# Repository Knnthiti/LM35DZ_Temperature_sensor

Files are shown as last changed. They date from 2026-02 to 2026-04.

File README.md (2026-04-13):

# Zero and Span Adjustment Circuit for LM35 Temperature Sensor

โปรเจกต์นี้เป็นการออกแบบและสร้างวงจรปรับแต่งสัญญาณ (Signal Conditioning) เพื่อแปลงแรงดันจากเซนเซอร์ **LM35** ให้เหมาะสมกับ ADC ของ Microcontroller โดยค่าที่ได้จากการทดลองอยู่ในช่วงประมาณ **0.218V – 0.507V** และแปลงเป็นค่า ADC ได้ประมาณ **0.64 – 3.10**

## 📐 รายละเอียดการคำนวณ (Calculation)

ข้อมูลในหัวข้อนี้อ้างอิงจาก **ผลการทดลองจริง** โดยสามารถดูแหล่งข้อมูลได้จากไฟล์ **กราฟการทดลอง.xlsx**

### 1. วิเคราะห์สัญญาณขาเข้า (Input Analysis)
ค่าที่วัดได้จากการทดลองจริงมีดังนี้:

| อุณหภูมิ (°C) | แรงดัน (V) | ADC |
|---:|---:|---:|
| 50 | 0.507 | 3.10 |
| 45 | 0.454 | 2.82 |
| 40 | 0.403 | 2.35 |
| 35 | 0.355 | 1.94 |
| 30 | 0.312 | 1.51 |
| 25 | 0.253 | 1.00 |
| 20 | 0.218 | 0.64 |

### 2. สมการเส้นตรง (Transfer Function)
ใช้รูปแบบสมการเส้นตรงแบบเดิมคือ
$$y = mx + c$$

โดย
- $m$ คือความชัน (Slope)
- $c$ คือจุดตัดแกน $y$ (Offset)

**2.1 การหาสมการ V_to_ADC**

กำหนดให้ $x = V$ และ $y = ADC$

- แทนค่าจากข้อมูลจริงในไฟล์ **กราฟการทดลอง.xlsx** (ใช้จุดปลายช่วงวัด)
  - จุดที่ 1: $(V, ADC) = (0.218, 0.64)$
  - จุดที่ 2: $(V, ADC) = (0.507, 3.10)$

- **หาค่าความชัน (Slope) แบบเดิม:**
  $$m = \frac{\Delta ADC}{\Delta V} = \frac{3.10 - 0.64}{0.507 - 0.218} = \frac{2.46}{0.289} = 8.5121$$

- **หาค่าออฟเซต (Intercept):**
  แทนค่าใน $y = mx + c$ ด้วยจุด $(0.218, 0.64)$
  $$0.64 = (8.5121 \times 0.218) + c$$
  $$0.64 = 1.8556 + c$$
  $$c = 0.64 - 1.8556 = -1.2156$$

- ตรวจสอบกับเส้นแนวโน้ม (Linear Trendline) จะได้ค่าเดียวกันคือ
  $$m = 8.5121,\; c = -1.2156$$

ดังนั้นสมการคือ
$$ADC = 8.5121V - 1.2156$$

**2.2 การหาสมการ ADC_to_C**

กำหนดให้ $x = ADC$ และ $y = C$

- จากการทำเส้นแนวโน้ม (Linear Trendline) ในไฟล์ **กราฟการทดลอง.xlsx** ได้ค่า
  $$m = 11.336,\; c = 13.106$$

ดังนั้นสมการคือ
$$C = 11.336(ADC) + 13.106$$

**สรุปสมการจากข้อมูลทดลองจริง (พร้อมกราฟ):**

1. **V_to_ADC**
   $$ADC = 8.5121V - 1.2156$$

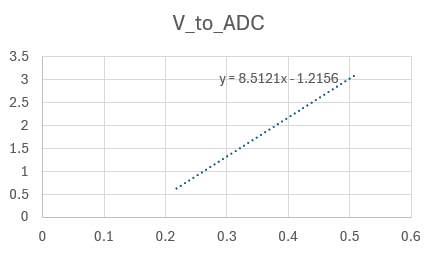
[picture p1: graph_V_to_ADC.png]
กราฟ V_to_ADC จากการทดลองจริง
   

2. **ADC_to_C**
   $$C = 11.336(ADC) + 13.106$$

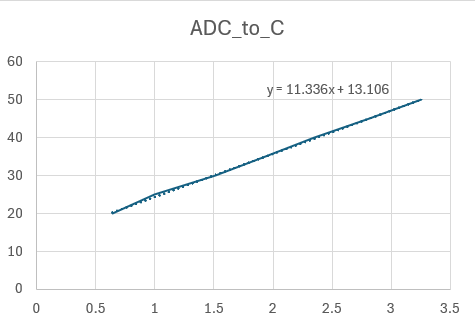
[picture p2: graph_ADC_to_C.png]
กราฟ ADC_to_C จากการทดลองจริง
   

จากภาพด้านบน ค่าที่ใช้ใน README เป็นค่าจริงจากการทดลอง และสามารถตรวจสอบรายละเอียดได้จากไฟล์ **กราฟการทดลอง.xlsx**

---

## 🛠 โครงสร้างและการทำงานของวงจร

วงจรนี้ใช้ Op-Amp **LM358** ในการจัดการสัญญาณ แบ่งออกเป็นส่วนต่างๆ ดังนี้:

- **Sensor Input:** รับสัญญาณจาก LM35-LP ที่ไฟเลี้ยง 3.3V
- **Input Buffer (U2A):** ทำหน้าที่เป็น Voltage Follower เพื่อแยกโหลดออกจากตัวเซนเซอร์
- **Zero Adjustment (U3A):** ใช้ Potentiometer (RV1) เพื่อปรับแรงดันอ้างอิง (Reference Voltage) สำหรับชดเชยค่า Offset
- **Span Adjustment (U3B):** ปรับอัตราขยาย (Gain) เพื่อให้ได้ช่วงแรงดันที่ต้องการ (Span)
- **Output:** สัญญาณ $V_{out}$ จะถูกส่งออกทาง Connector J1

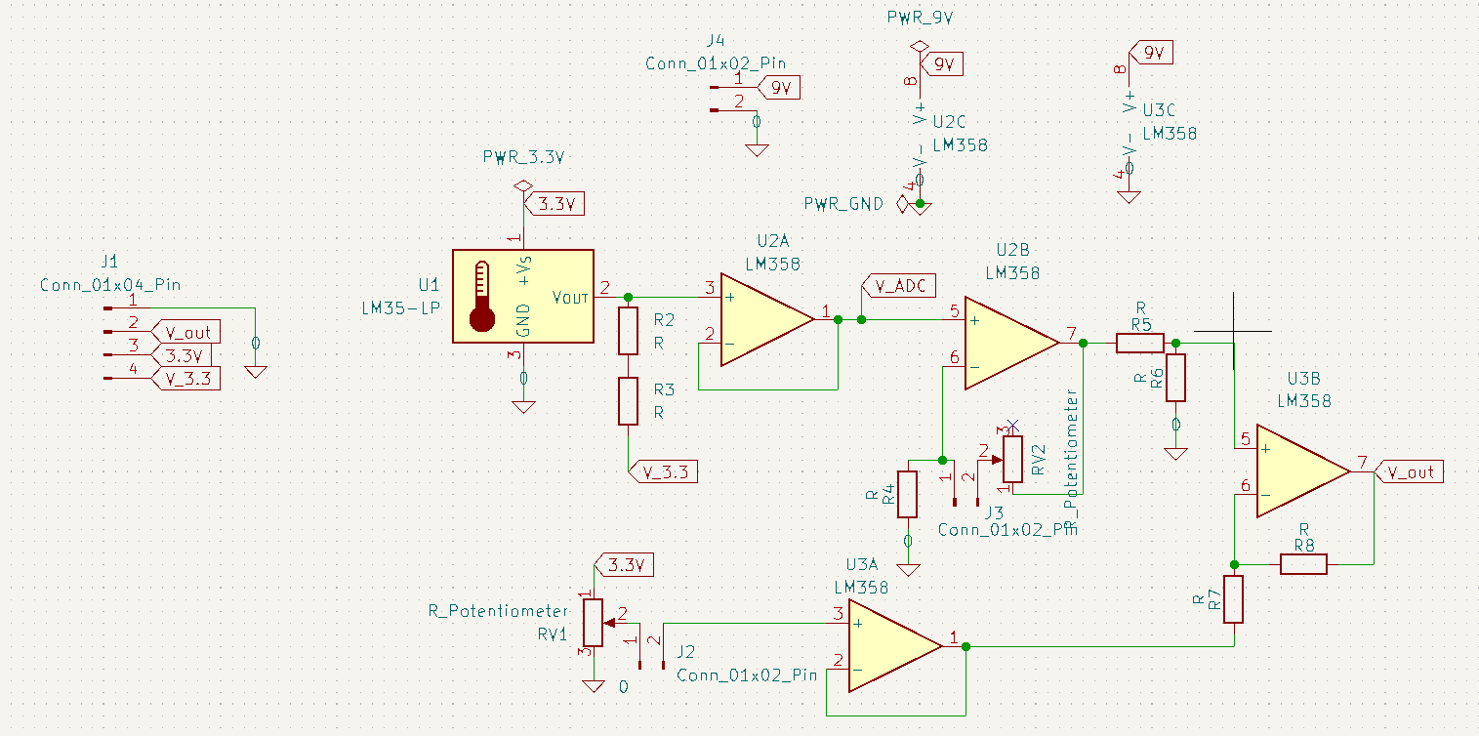
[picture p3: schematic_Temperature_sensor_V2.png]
Operational amplifier differential amplifier circuit diagram


## 📊 ระบบแสดงข้อมูล (Display System)

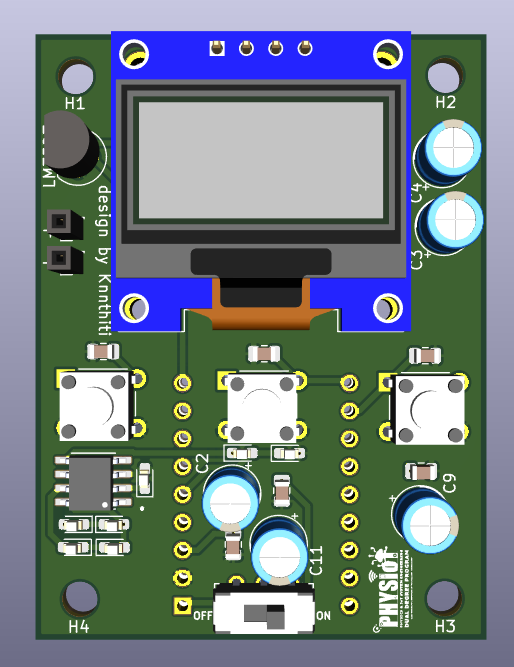
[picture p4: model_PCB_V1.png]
3D model overview


ระบบแสดงผลถูกแบ่งเป็น 3 โหมดตามปุ่มควบคุม ดังนี้:
- **ปุ่มซ้าย:** เข้าโหมด **WiFi Manager** และเมื่อเชื่อมต่อเครือข่ายสำเร็จ ระบบจะแสดง **IP Address** สำหรับเชื่อมต่อผ่าน **WebSocket**
- **ปุ่มกลาง:** แสดงค่า **อุณหภูมิ** ที่วัดได้จากเซนเซอร์
- **ปุ่มขวา:** แสดงค่า **แรงดันไฟฟ้า** ของสัญญาณที่วัดได้

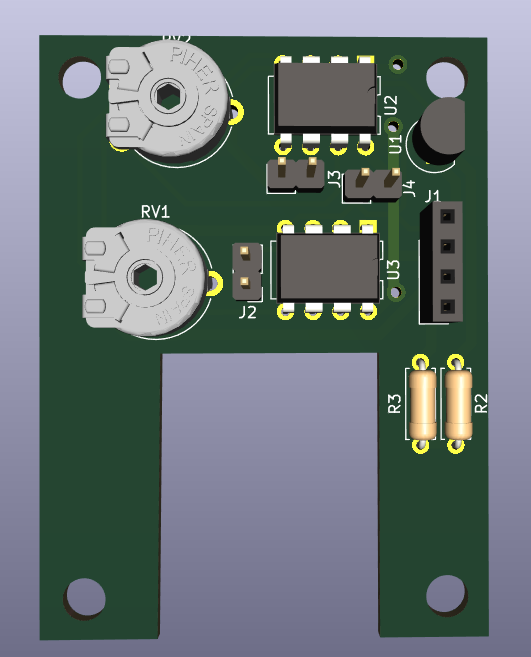
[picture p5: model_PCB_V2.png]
3D model overview


เป็น Zero and span adjustment circuit :
- **R ตัวบน:** เป็น Rf ปรับกำลังขยาย
- **R ตัวล่าง:** เป็น span ปรับแรงดัน

โค้ดโปรแกรมสามารถดูได้ที่ไฟล์ `T_sensor_V3/T_sensor_V3.ino`

---

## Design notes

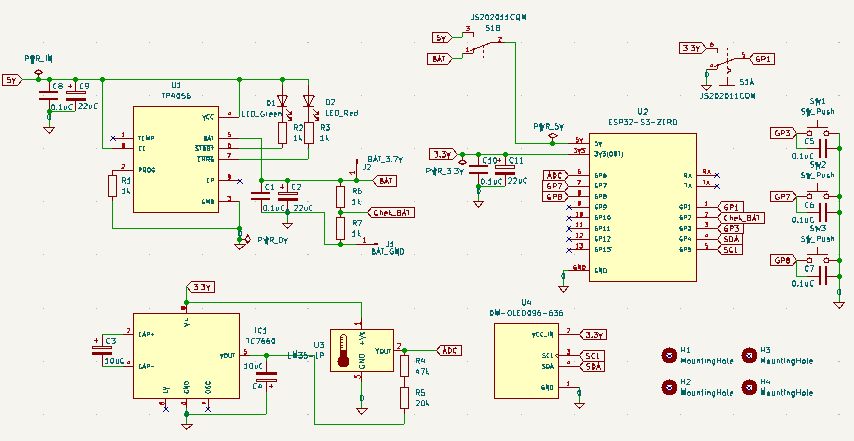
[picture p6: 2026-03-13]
schematic_Temperature_sensor_V1.png

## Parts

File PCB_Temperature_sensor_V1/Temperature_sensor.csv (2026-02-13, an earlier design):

Source: | C:\Users\Knnn\Desktop\LM35DZ_Temperature_sensor\Temperature_sensor\Temperature_sensor.kicad_sch
Date: | 2026-02-13T22:16:05+0700
Tool: | Eeschema 8.0.5
Generator: | C:\Users\Knnn\AppData\Local\Programs\KiCad\8.0\bin\scripting\plugins/bom_csv_grouped_by_value_with_fp.py
Component Count: | 31
Ref | Qnty | Value | Cmp name | Footprint | Description | Vendor | DNP
C1, C5, C6, C7, C8, C10 | 6 | 0.1uC | C | Capacitor_SMD:C_0805_2012Metric | Unpolarized capacitor
C2, C9, C11 | 3 | 22uC | C_Polarized | Capacitor_THT:CP_Radial_D5.0mm_P2.00mm | Polarized capacitor
C3, C4 | 2 | 10uC | C_Polarized | Capacitor_THT:CP_Radial_D5.0mm_P2.00mm | Polarized capacitor
D1 | 1 | LED_Green | LED | LED_SMD:LED_0603_1608Metric_Pad1.05x0.95mm_HandSolder | Light emitting diode
D2 | 1 | LED_Red | LED | LED_SMD:LED_0603_1608Metric_Pad1.05x0.95mm_HandSolder | Light emitting diode
IC1 | 1 | TC7660 | TC7660 | TC7660:TC7660
J1 | 1 | BAT_GND | Conn_01x01_Pin | Connector_PinSocket_2.00mm:PinSocket_1x01_P2.00mm_Vertical | Generic connector, single row, 01x01, script generated
J2 | 1 | BAT_3.7V | Conn_01x01_Pin | Connector_PinSocket_2.00mm:PinSocket_1x01_P2.00mm_Vertical | Generic connector, single row, 01x01, script generated
R1, R2, R3, R6, R7 | 5 | 1k | R | LED_SMD:LED_0603_1608Metric_Pad1.05x0.95mm_HandSolder | Resistor
R4 | 1 | 47k | R | Resistor_THT:R_Axial_DIN0207_L6.3mm_D2.5mm_P10.16mm_Horizontal | Resistor
R5 | 1 | 20k | R | Resistor_THT:R_Axial_DIN0207_L6.3mm_D2.5mm_P10.16mm_Horizontal | Resistor
S1 | 1 | JS202011CQN | JS202011CQN | JS202011CQN:JS202011CQN
SW1, SW2, SW3 | 3 | SW_Push | SW_Push | SW_Push:SW_TH_Tactile_Omron_B3F-10xx | Push button switch, generic, two pins
U1 | 1 | TP4056 | TP4056 | TP4056:SOP127P600X175-9N
U2 | 1 | ESP32-S3-ZERO | ESP32-S3-ZERO | esp32s3Zero:MODULE_ESP32-S3-ZERO
U3 | 1 | LM35-LP | LM35-LP | Package_TO_SOT_THT:TO-92 | Precision centigrade temperature sensor, TO-92
U4 | 1 | DM-OLED096-636 | DM-OLED096-636 | OLED:MODULE_DM-OLED096-636

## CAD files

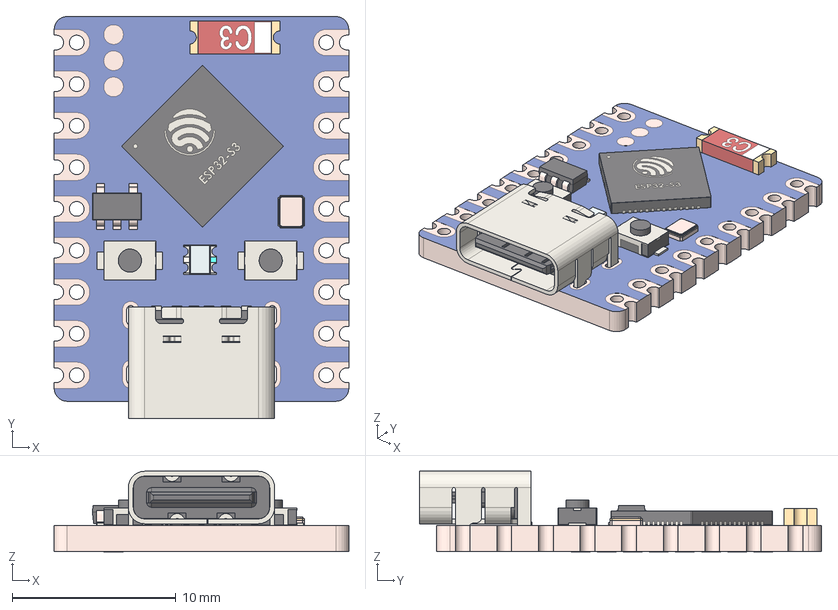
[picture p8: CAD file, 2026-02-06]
Components/esp32s3Zero/ESP32-S3_Zero.step
18.0 x 24.6 x 4.92 mm

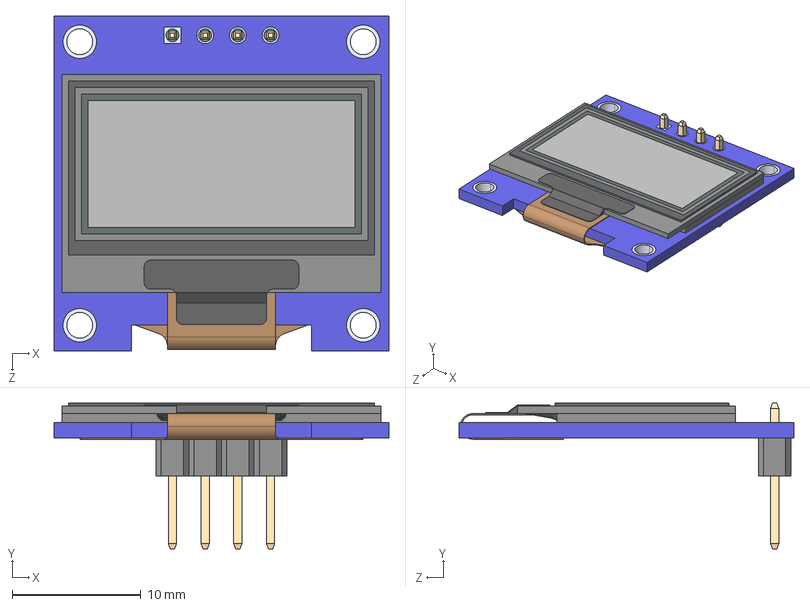
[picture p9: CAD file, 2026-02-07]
Components/OLED/DM-OLED096-636.step
26.0 x 11.3 x 26.0 mm
DM-OLED096-636_Module
DM-OLED096-636_Panel

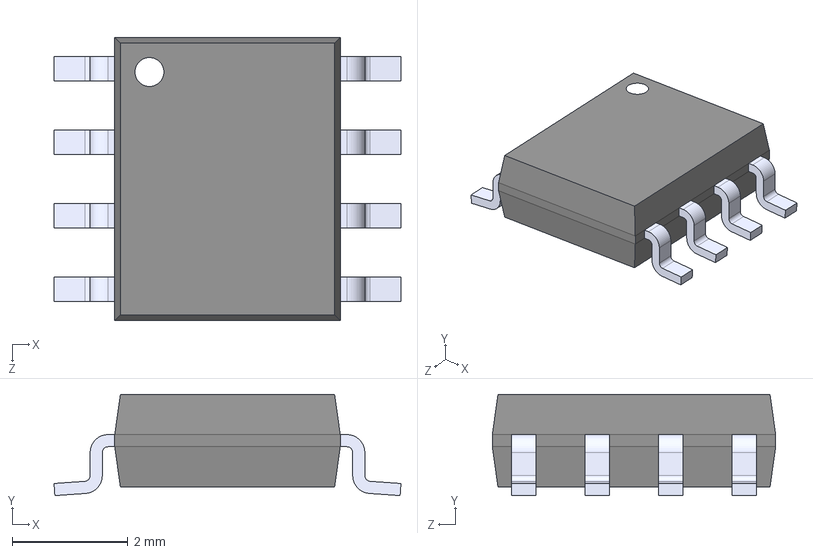
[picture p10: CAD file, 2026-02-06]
Components/TP4056_IC/TP4056.step
6.00 x 1.75 x 4.90 mm

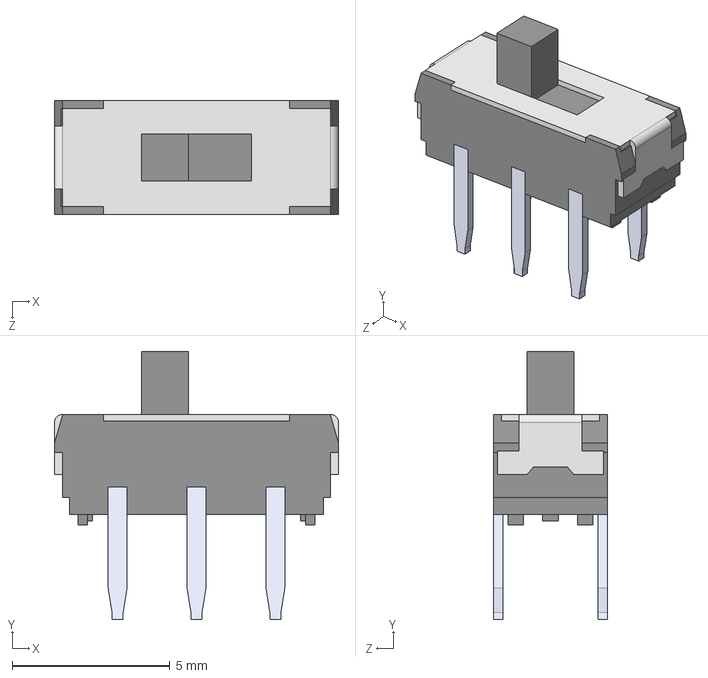
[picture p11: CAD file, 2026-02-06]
Components/swith/JS202011CQN.step
9.00 x 8.50 x 3.60 mm

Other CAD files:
Components/TC7660/dip8_ic.STEP

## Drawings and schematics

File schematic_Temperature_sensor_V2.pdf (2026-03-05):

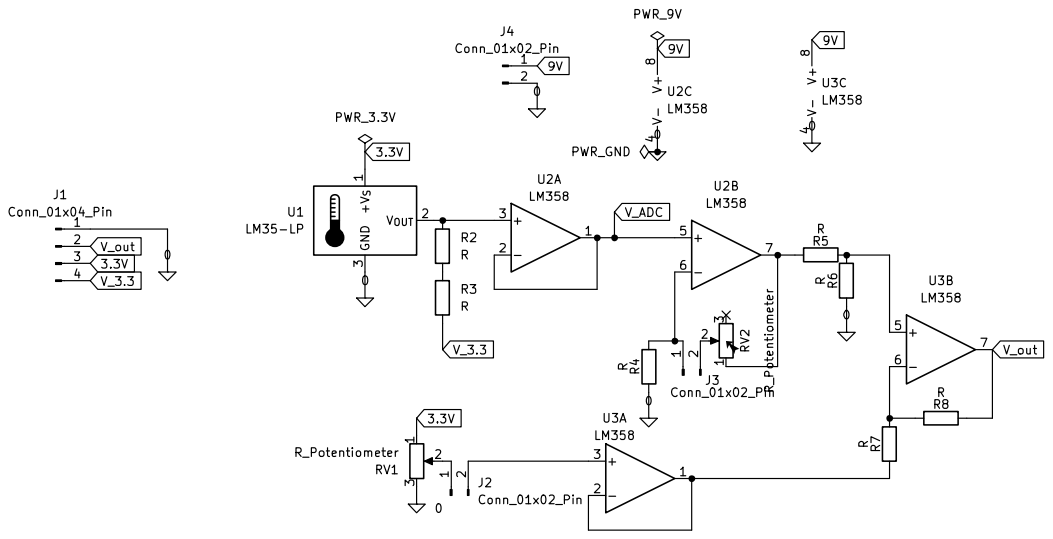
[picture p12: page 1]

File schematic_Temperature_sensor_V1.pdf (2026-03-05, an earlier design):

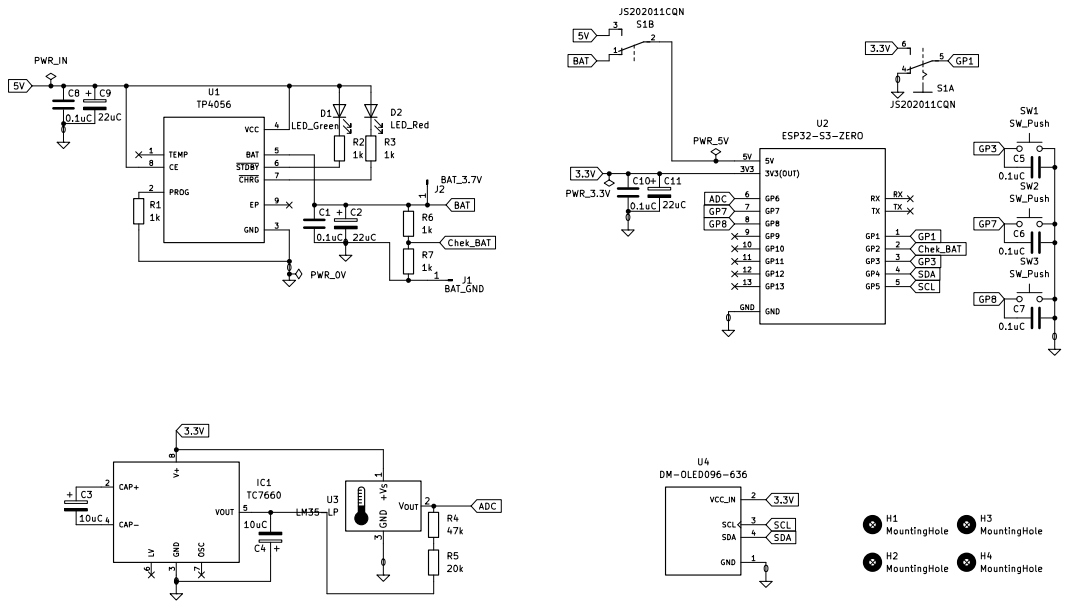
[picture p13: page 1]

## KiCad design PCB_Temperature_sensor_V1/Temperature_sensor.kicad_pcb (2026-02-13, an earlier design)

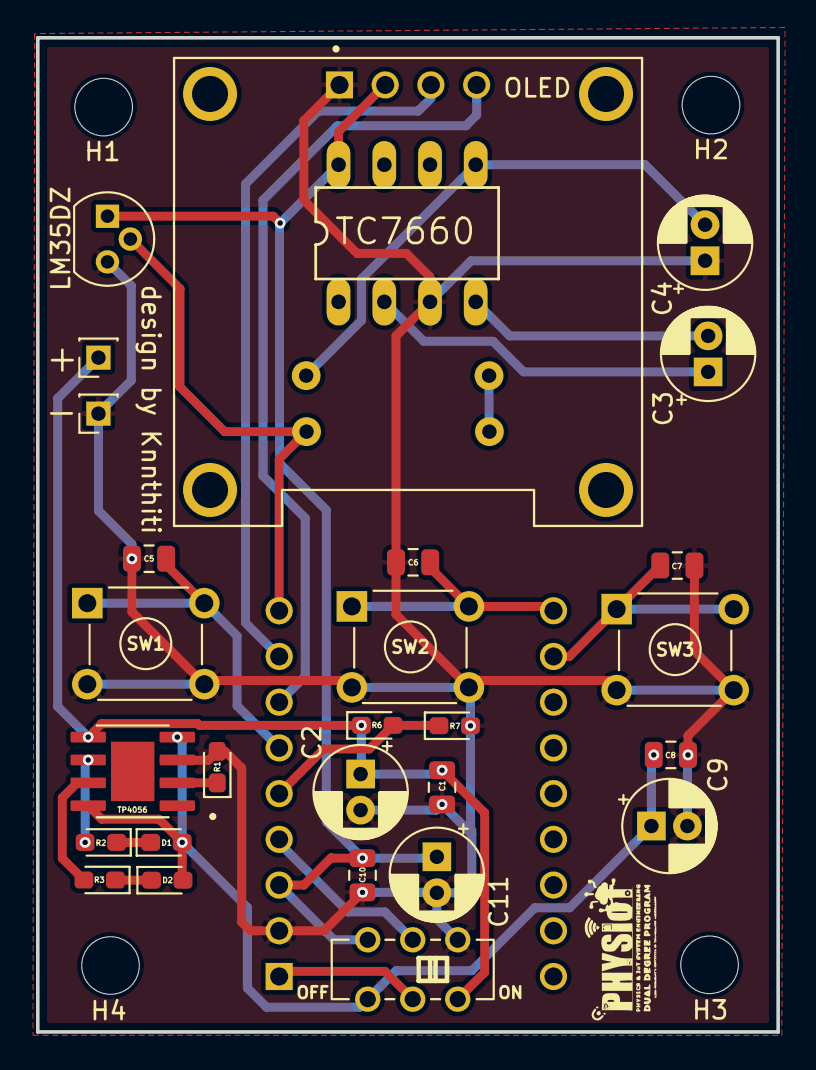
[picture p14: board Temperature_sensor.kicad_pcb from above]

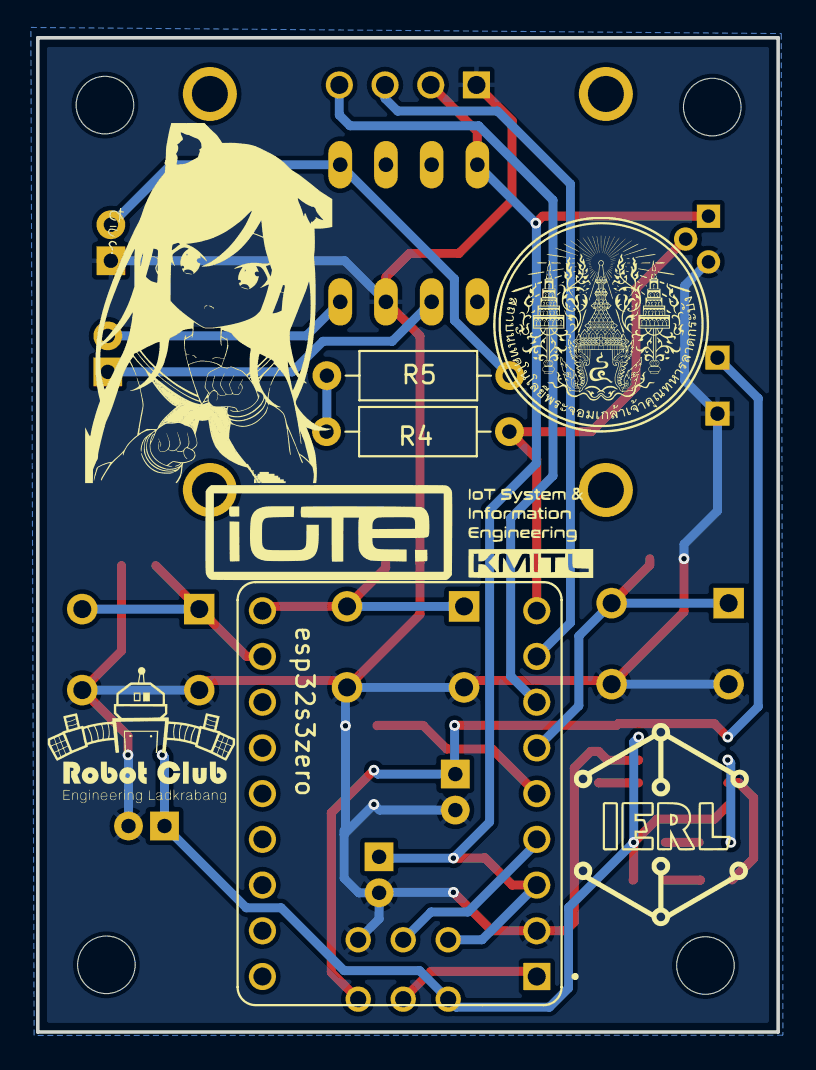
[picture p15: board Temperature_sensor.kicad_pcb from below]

Board: 2 copper layers, 41.1 x 55.2 mm, 35 parts (3 on the bottom side), 22 nets.

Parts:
+: BAT_3.7V; PinSocket_1x01_P2.00mm_Vertical
-: BAT_GND; PinSocket_1x01_P2.00mm_Vertical
C1, C5, C6, C7, C8, C10: 0.1uC; C_0805_2012Metric
C2, C9, C11: 22uC; CP_Radial_D5.0mm_P2.00mm
C3, C4: 10uC; CP_Radial_D5.0mm_P2.00mm
D1: LED_Green; LED_0603_1608Metric_Pad1.05x0.95mm_HandSolder
D2: LED_Red; LED_0603_1608Metric_Pad1.05x0.95mm_HandSolder
H1, H2, H3, H4: MountingHole; MountingHole_3.2mm_M3
LM35DZ: LM35-LP; TO-92
OFF                   ON: JS202011CQN
OLED: DM-OLED096-636; MODULE_DM-OLED096-636
R1, R2, R3, R6, R7: 1k; LED_0603_1608Metric_Pad1.05x0.95mm_HandSolder
R4: 47k; R_Axial_DIN0207_L6.3mm_D2.5mm_P10.16mm_Horizontal
R5: 20k; R_Axial_DIN0207_L6.3mm_D2.5mm_P10.16mm_Horizontal
SW1, SW2, SW3: SW_Push; SW_TH_Tactile_Omron_B3F-10xx
TC7660: TC7660
TP4056: TP4056; SOP127P600X175-9N
esp32s3zero: ESP32-S3-ZERO; MODULE_ESP32-S3-ZERO

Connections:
0: -.1, C1.2, C2.2, C4.1, C5.2, C6.2, C7.2, C8.2, C9.2, C10.2, C11.2, LM35DZ.3 (GND), OFF ON.4, OLED.1 (GND), R1.2, R7.2, SW1.2, SW2.2, SW3.2, TC7660.3 (GND), TP4056.3 (GND), esp32s3zero.GND
3.3V: C10.1, C11.1, LM35DZ.1 (+V_{S}), OFF ON.6, OLED.2 (VCC_IN), TC7660.8 (V+), esp32s3zero.3V3 (3V3(OUT))
5V: C8.1, C9.1, D1.2 (A), D2.2 (A), OFF ON.3, TP4056.4 (VCC), TP4056.8 (CE)
ADC: LM35DZ.2 (V_{OUT}), R4.1, esp32s3zero.6 (GP6)
BAT: +.1, C1.1, C2.1, OFF ON.1, R6.1, TP4056.5 (BAT)
Chek_BAT: R6.2, R7.1, esp32s3zero.2 (GP2)
GP1: OFF ON.5, esp32s3zero.1 (GP1)
GP3: C5.1, SW1.1, esp32s3zero.3 (GP3)
GP7: C6.1, SW2.1, esp32s3zero.7 (GP7)
GP8: C7.1, SW3.1, esp32s3zero.8 (GP8)
unnamed: D1.1 (K), R2.1
unnamed: D2.1 (K), R3.1
unnamed: C3.1, TC7660.2 (CAP+)
unnamed: C3.2, TC7660.4 (CAP-)
unnamed: C4.2, R5.2, TC7660.5 (VOUT)
unnamed: R4.2, R5.1
unnamed: OFF ON.2, esp32s3zero.5V
unnamed: R1.1, TP4056.2 (PROG)
unnamed: R3.2, TP4056.7 (~CHRG)
unnamed: R2.2, TP4056.6 (~STDBY)
SCL: OLED.3 (SCL), esp32s3zero.5 (GP5)
SDA: OLED.4 (SDA), esp32s3zero.4 (GP4)

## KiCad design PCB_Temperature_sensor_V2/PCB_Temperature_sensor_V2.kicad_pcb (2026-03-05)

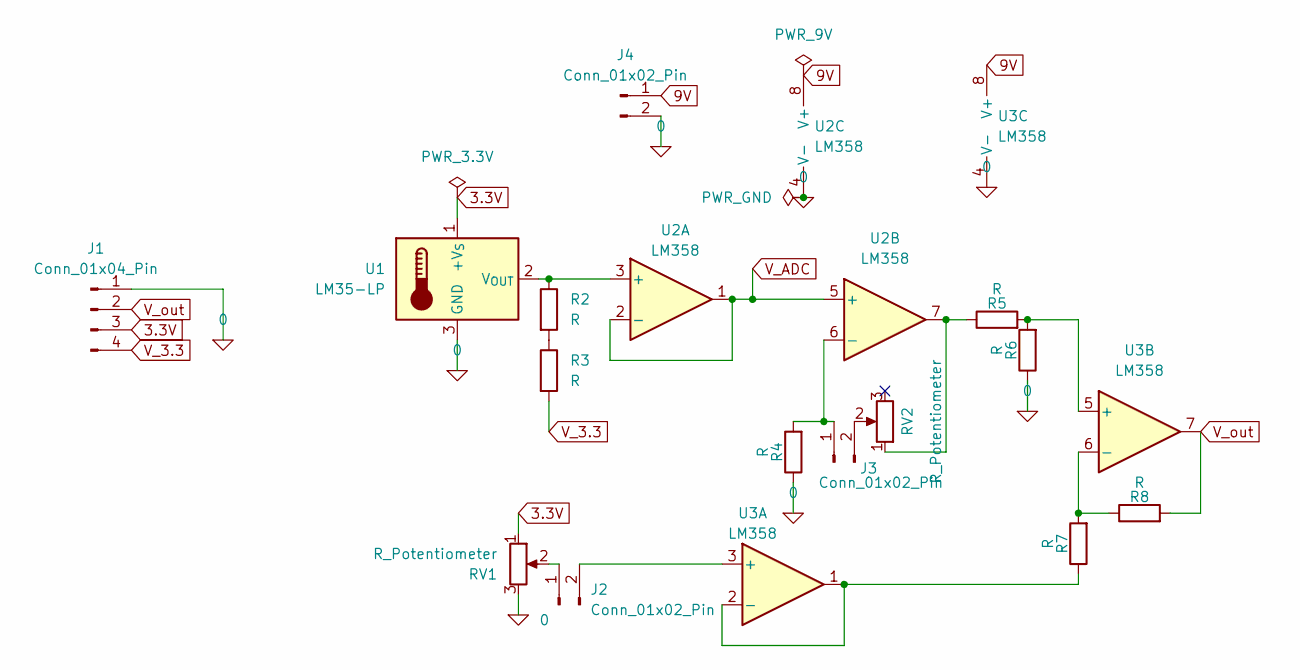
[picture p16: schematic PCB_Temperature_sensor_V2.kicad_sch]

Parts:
J1: Conn_01x04_Pin; PinSocket_1x04_P2.54mm_Vertical
J2, J3, J4: Conn_01x02_Pin; PinHeader_1x02_P2.54mm_Vertical
R2, R3: R; R_Axial_DIN0207_L6.3mm_D2.5mm_P7.62mm_Horizontal
R4, R5, R6, R7, R8: R; R_0603_1608Metric_Pad0.98x0.95mm_HandSolder
RV1, RV2: R_Potentiometer; Potentiometer_Piher_PT-10-V10_Vertical
U1: LM35-LP; TO-92_Inline
U2, U3: LM358; DIP-8_W7.62mm

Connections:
0: J1.1, J4.2, R4.1, R6.1, RV1.3, U1.3 (GND), U2.4 (V-), U3.4 (V-)
3.3V: J1.3, RV1.1, U1.1 (+V_{S})
9V: J4.1, U2.8 (V+), U3.8 (V+)
unnamed: J2.1, RV1.2
unnamed: J2.2, U3.3 (+)
unnamed: J3.1, R4.2, U2.6 (-)
unnamed: J3.2, RV2.2
unnamed: R2.2, R3.1
unnamed: R5.1, RV2.1, U2.7
unnamed: R2.1, U1.2 (V_{OUT}), U2.3 (+)
unnamed: R7.1, U3.1, U3.2 (-)
unnamed: R5.2, R6.2, U3.5 (+)
unnamed: R7.2, R8.1, U3.6 (-)
V_3.3: J1.4, R3.2
V_ADC: U2.1, U2.2 (-), U2.5 (+)
V_out: J1.2, R8.2, U3.7

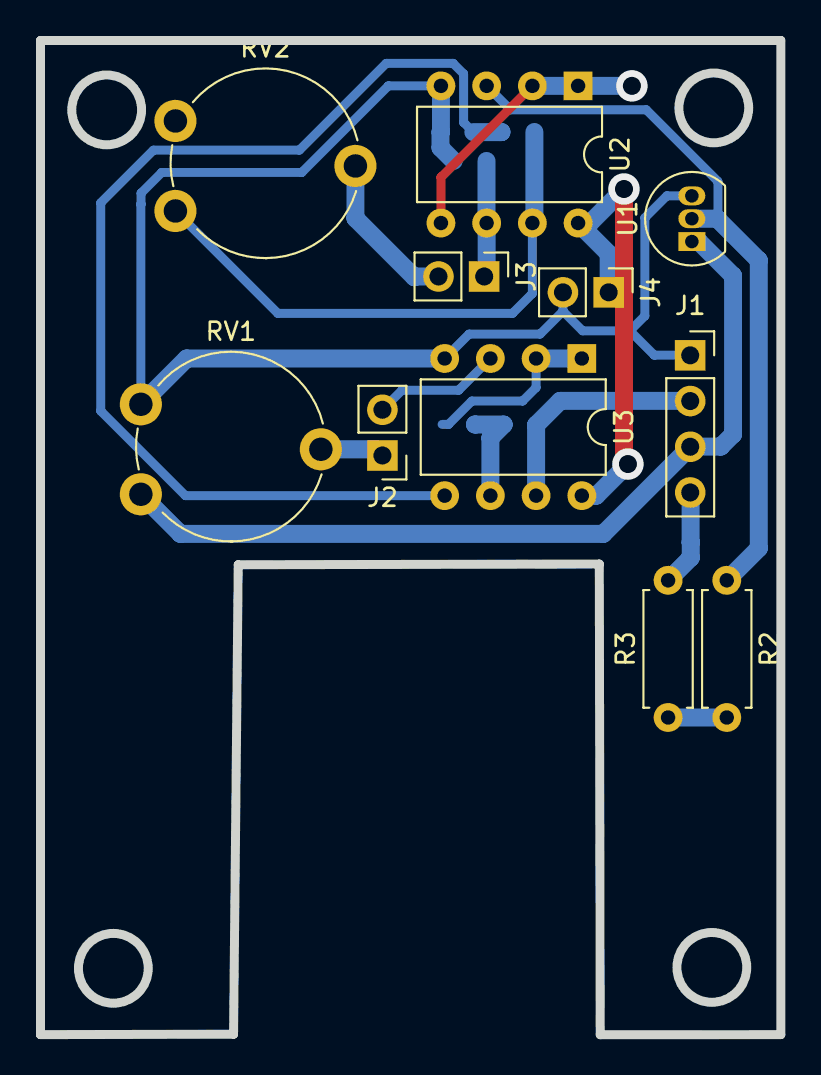
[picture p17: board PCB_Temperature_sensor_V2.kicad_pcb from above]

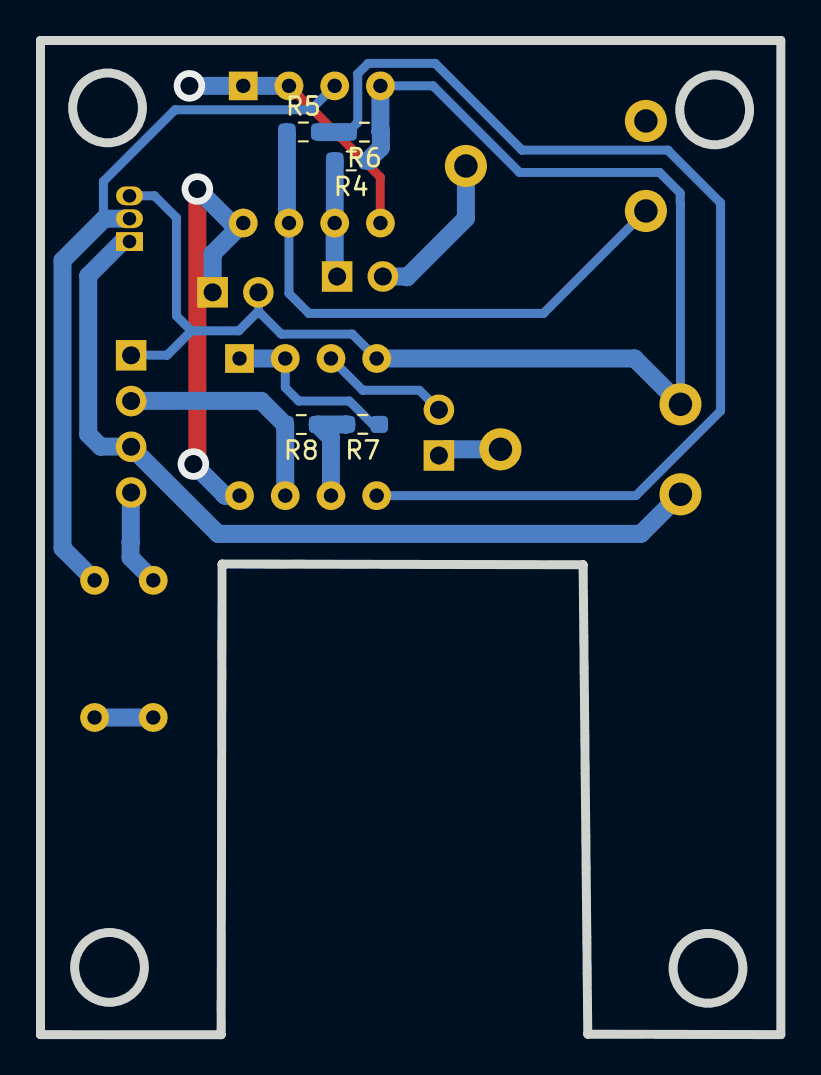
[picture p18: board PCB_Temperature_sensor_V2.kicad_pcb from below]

Board: 2 copper layers, 41.1 x 55.2 mm, 16 parts (5 on the bottom side), 16 nets.

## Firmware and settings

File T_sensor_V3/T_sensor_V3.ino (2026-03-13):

#include <WiFi.h>
#include <WebServer.h>
#include <WebSocketsServer.h>
#include <WiFiManager.h>
#include <Wire.h>
#include <Adafruit_GFX.h>
#include <Adafruit_SSD1306.h>
#include <driver/adc.h>

// --- Config Pins ---
#define I2C_SDA 4
#define I2C_SCL 5
#define ADC_SCOPE_PIN ADC1_CHANNEL_5  // GPIO 6
#define BTN_WIFI 3
#define BTN_TEMP 7     // ปุ่มดูอุณหภูมิ
#define BTN_VOLTAGE 8  // ปุ่มดูแรงดัน

// --- Objects ---
Adafruit_SSD1306 display(128, 64, &Wire, -1);
WebServer server(80);
WebSocketsServer webSocket = WebSocketsServer(81);

// --- Variables ---
enum DeviceMode { IDLE,
                  MODE_WIFI,
                  MODE_TEMP,
                  MODE_VOLTAGE };
DeviceMode currentMode = IDLE;

// === นำเข้าไฟล์หน้าเว็บ HTML ===
#include "html_page.h" 

uint32_t raw_value_1 = 0;
uint32_t raw_value_avg = 0;
float V = 0;

// --- 1. ฟังก์ชันจัดการหน้าจอ OLED ---
void updateDisplay(String title, String line1, String line2) {
  display.clearDisplay();
  display.setTextSize(1);
  display.setTextColor(SSD1306_WHITE);
  display.setCursor(0, 0);
  display.println(title);
  display.drawFastHLine(0, 10, 128, SSD1306_WHITE);
  display.setCursor(0, 20);
  display.println(line1);
  display.setCursor(0, 35);
  display.println(line2);
  display.display();
}

// --- 2. ฟังก์ชัน WiFiManager Callback ---
void configModeCallback(WiFiManager *myWiFiManager) {
  updateDisplay("WIFI CONFIG",
                "SSID: " + myWiFiManager->getConfigPortalSSID(),
                "PASS: 12345678");
}

// --- 3. ฟังก์ชันเริ่มระบบ Network ---
void startNetwork() {
  server.on("/", []() {
    // ส่งข้อมูล webpageCode ที่ถูกดึงมาจาก html_page.h
    server.send(200, "text/html", webpageCode);
  });
  server.begin();
  webSocket.begin();
  Serial.println("Network Services Started");
}

// --- 4. ฟังก์ชันจัดการ WiFi ---
void runWiFiManager(bool forceConfig) {
  currentMode = MODE_WIFI;
  WiFiManager wm;
  
  // ตั้งค่า Timeout ให้ Config Portal (ถ้าไม่มีคนต่อภายใน 60 วิ จะหลุดกลับไปทำ loop ต่อ)
  wm.setConfigPortalTimeout(60); 
  
  wm.setAPCallback(configModeCallback);

  bool res;
  if (forceConfig) {
    res = wm.startConfigPortal("AutoConnectAP", "12345678");
  } else {
    res = wm.autoConnect("AutoConnectAP", "12345678");
  }

  if (res) {
    updateDisplay("CONNECTED", "http://" + WiFi.localIP().toString(), " ");
    delay(2000);
    startNetwork();
  } else {
    // กรณีที่ Timeout หรือหลุดจากการตั้งค่า
    Serial.println("Failed to connect or hit timeout");
    currentMode = IDLE; // กลับไปโหมดว่าง
    updateDisplay("WIFI TIMEOUT", "Press button to", "select mode");
    delay(2000);
  }
}

// --- 5. ฟังก์ชันคำนวณแรงดันและอุณหภูมิ ---
float Get_Voltage() {
  for (uint16_t i = 0; i < 1000; i++) {
    raw_value_avg += adc1_get_raw(ADC_SCOPE_PIN);
    delay(1);
  }

  raw_value_1 = raw_value_avg / 1000;
  raw_value_avg = 0;

  // bit_to_V
  V = (float)(map(raw_value_1, 0, 4096, 0, 3180));
  if(V < 1000){
    V += 100;
  }else{
    V += 200;
  }

  if(V > 3000){
    V -= 120;
  }

  V = V/1000.0;

  Serial.println(V ,3);
  return V;
}

float Get_Temperature() {
  // 1. ดึงค่าแรงดันปัจจุบันมาคูณ 1000 เพื่อทำเป็นมิลลิโวลต์ (mV) 
  // (จำเป็นต้องแปลงเป็นจำนวนเต็มเพื่อให้ทำงานกับ map() ได้แม่นยำ)
  long mV = Get_Voltage() * 1000;

  // 2. แมปค่าจากช่วงแรงดัน (500 - 3100 mV) เป็นช่วงอุณหภูมิ (2000 - 5000)
  long temp_mapped = map(mV, 640, 3260, 2000, 5000);

  // 3. หารด้วย 100.0 เพื่อคืนค่ากลับเป็นเลขทศนิยม (เช่น 2550 / 100.0 = 25.50 °C)
  return (float)temp_mapped / 100.0;
}

// --- 6. ฟังก์ชันแสดงผลบนจอ OLED ---
void Print_Voltage() {
  float voltage = Get_Voltage();
  display.clearDisplay();
  display.setTextSize(3);
  display.setCursor(10, 25);
  display.print(voltage, 2);
  display.print(" V");
  display.display();
}

void Print_Temperature() {
  // ไม่ต้องแนบค่า voltage เข้าไปในวงเล็บแล้ว เพราะฟังก์ชันจะไปอ่าน ADC เอง
  float temp = Get_Temperature(); 
  display.clearDisplay();
  display.setTextSize(3);
  display.setCursor(10, 25);
  display.print(temp, 1);
  display.print(" C");
  display.display();
}

void setup() {
  Serial.begin(115200);
  pinMode(BTN_WIFI, INPUT_PULLUP);
  pinMode(BTN_TEMP, INPUT_PULLUP);
  pinMode(BTN_VOLTAGE, INPUT_PULLUP);
  pinMode(1, INPUT); // ปุ่มสำหรับสลับโหมดหลัก/พักจอ

  Wire.begin(I2C_SDA, I2C_SCL);
  if (!display.begin(SSD1306_SWITCHCAPVCC, 0x3C)) {
    for (;;) ;
  }

  adc1_config_width(ADC_WIDTH_BIT_12);
  adc1_config_channel_atten(ADC_SCOPE_PIN, ADC_ATTEN_DB_11);

  updateDisplay("STARTING...", "Connecting WiFi...", "Please wait");
  runWiFiManager(false); // เรียกครั้งแรกตอนบูต (พยายามต่ออันเก่า)
}

void loop() {
  if (digitalRead(1) == 0) {
    // โหมดตั้งค่า WiFi (GPIO 3)
    if (digitalRead(BTN_WIFI) == LOW) {
      delay(200); // Debounce
      // ถ้ากดปุ่ม WiFi เราจะไม่ restart ห้วนๆ แล้ว แต่จะเรียก WiFiManager ขึ้นมาเลย
      runWiFiManager(true);
    }

    // โหมดแสดงอุณหภูมิ (GPIO 7)
    if (digitalRead(BTN_TEMP) == LOW) {
      delay(200); // Debounce
      currentMode = MODE_TEMP;
    }

    // โหมดแสดงแรงดัน (GPIO 8)
    if (digitalRead(BTN_VOLTAGE) == LOW) {
      delay(200); // Debounce
      currentMode = MODE_VOLTAGE;
    }

    // --- อัปเดตการทำงานตามโหมด ---
    if (currentMode == MODE_VOLTAGE) {
      Print_Voltage();
    } 
    else if (currentMode == MODE_TEMP) {
      Print_Temperature();
    } 
    else if (currentMode == MODE_WIFI) {
      // โหมดนี้จะทำงานเมื่อ WiFi เชื่อมต่อสำเร็จแล้วเท่านั้น
      static unsigned long lastWS = 0;
      if (millis() - lastWS > 100) {
        float v = Get_Voltage();
        float t = Get_Temperature(); 

        // ส่งข้อมูลเป็น JSON
        String json = "{\"v\":" + String(v, 3) + ",\"t\":" + String(t, 2) + "}";
        webSocket.broadcastTXT(json);
        lastWS = millis();
      }
      webSocket.loop();
      server.handleClient();
      
      // อัปเดตหน้าจอให้รู้ว่าอยู่ในโหมด WiFi พร้อมส่งค่า
      display.clearDisplay();
      display.setTextSize(1);
      display.setCursor(0, 0);
      display.print("IP: "); display.println(WiFi.localIP());
      display.setCursor(0, 15);
      display.print("V: "); display.print(v, 2);
      display.setCursor(0, 30);
      display.print("T: "); display.print(t, 2);
      display.display();
    }
  } else {
    // กรณีที่ GPIO 1 เป็น High (พักหน้าจอ)
    display.clearDisplay();
    display.fillTriangle(44+22, 22+3,  44+12, 22+13, 44+22, 22+13, SSD1306_WHITE);
    display.fillTriangle(44+22, 22+12, 44+32, 22+12, 44+22, 22+22, SSD1306_WHITE);
    display.display();
  }
}
